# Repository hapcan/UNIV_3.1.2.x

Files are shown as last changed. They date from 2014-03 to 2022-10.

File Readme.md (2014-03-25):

UNIV 3.1.2.x
============

TOUCH BUTTON MODULE - 6 sensors &amp; 1-wire temperature sensor

Device webpage: http://hapcan.com/devices/universal/univ_3/univ_3-1-2-x/

Hardware created in Eagle PCB Software http://www.cadsoftusa.com/

Firmware created in Microchip MPLAB http://www.microchip.com/mplabide/ in assembly language

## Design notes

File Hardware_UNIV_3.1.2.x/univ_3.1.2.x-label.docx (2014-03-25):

| | TOUCH BUTTON TYPE UNIV 3.1.2.x S/N 0000056Ah
| | PRZYCISK DOTYKOWY TYP UNIV 3.1.2.x S/N 0000056Ah

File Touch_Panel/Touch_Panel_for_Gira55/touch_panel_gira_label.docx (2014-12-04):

| OFF 18° 21° HAPCAN | HAPCAN

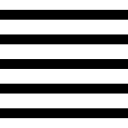
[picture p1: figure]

| 15min
HAPCAN | | Icons thanks to http://icons8.com/
How to prepare touch panel labels 1. Print required design on adhesive transparent foil and let it dry 2. Cut A4 page along the red line into single labels 3. Put another protective adhesive transparent foils on top of the printed ones 4. Cut the label to the required size along the light gray line 5. Stick the label on the Touch Panel and press it precisely 6. Cut temperature sensor hole using thin saw file with the sharp end | Instrukcja wykonania etykiety panelu dotykowego 1. Wydrukuj przygotowaną etykietę na samoprzylepnej przezroczystej folii i pozwól jej wyschnąć 2. Rozetnij stronę A4 wzdłuż czerwonej linii na pojedyncze etykiety 3. Przyklej jeszcze jedną ochronną wierzchnią warstwę samoprzylepnych folii na wydrukowane etykiety 4. Przytnij etykietę do wymaganego rozmiaru wzdłuż jasnoszarej linii 5. Przyklej etykietę na panel dotykowy i starannie dociśnij 6. Wytnij otwór sensora temperatury używając cienkiego okrągłego pilnika modelarskiego z ostrym końcem

This template link: https://github.com/hapcan/UNIV_3.1.2.x/blob/master/Touch_Panel/Touch_Panel_for_Gira55/touch_panel_gira_label.docx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

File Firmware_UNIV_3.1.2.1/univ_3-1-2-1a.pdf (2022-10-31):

## BACK BOX TOUCH BUTTON FIRMWARE

# UNIV 3.1.2.1

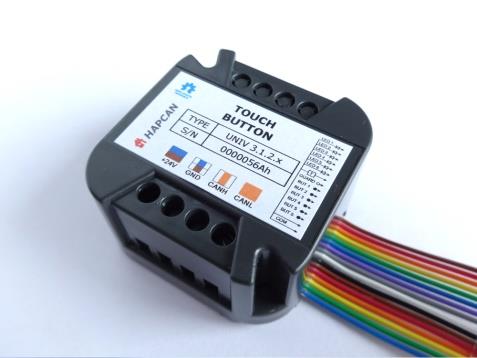
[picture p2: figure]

© 2017 hapcan.com | univ_3-1-2-1a.pdf - page 1 / 9

### 1. Features

- 6 channel touch button module.
- Another button is recognized when all sensors are touched at the same time.
- 7 types of button behaving is recognized: button pressed, released, pressed for 400ms, pressed for 4s, released within 400ms, released between 400ms and 4s, released after 4s
- There is a 20ms reaction time. Button has to be pressed for at least 20ms to activate module. It avoids contacts bouncing.
- 6 LEDs can be connected to indicate status of other devices on the network.
- Included temperature, thermostat and PWM controller feature when Dallas sensor is connected.
- Temperature measurement in range -55°C to +125°C with 0.0625°C resolution
- Setpoint value in range -55°C to +125° C with 0.0625°C resolution
- Hysteresis value adjustable from 0.0625 to 16.000°C with 0.0625°C resolution
- 10 control instructions
- 3 blocking instructions
- Allows defining up to 128 CAN messages which can indirectly control the module
- Self-control feature – pressed button can control LEDs in the same module
- Allows writing notes in the processor memory
- Uptime counter
- Health check monitor
- Transmit (42 messages) and receive (42 messages) FIFO buffers

### 2. Compatibility

- Firmware for UNIV 3.1.2.x module
- Firmware can be uploaded into processor with bootloader version 3.1 or compatible.
- Firmware is not fully compatible with previous UNIV 3.1.2.0. The temperature sensor parameters must be configure again.

### 3. Firmware version

UNIV | 3 | . | 1 | . | 2 | . | 1
firmware version
application version (back box touch button) application type (button)
processor version
universal processor

### 4. Communication Frames (messages)

### 4.1. Button message

Module sends message to the bus, when status of input changes. Module is able to distinguish a few types of button behaving: pressed, released, pressed for 400ms, pressed for 4s, released within 400ms, released between 400ms and 4s , released after 4s. For each situation the unique message is sent to the bus. It is possible to choose for each button separately what massages should be sent. Button 7 is recognized when all sensors are touched at the same time.
This firmware controls LEDs connected to switches. LED can be toggled by message received from the bus or locally by pressed button.

Table 1. BUTTON frame (0x301)
Frame type | Flags | Module | Group | D0 | D1 | D2 | D3 | D4 | D5 | D6 | D7
0x301 | 3 | 2 | 1 | 0 | Node Nr | Group Nr | 0xFF | 0xFF | CHANNEL | BUTTON | LED | 0xFF | 0xFF | 0xFF
0x301 | – universal module frame, button
3 | - | - not used flag, read as “0”
2 | - | - not used flag, read as “0”
1 | - | - not used flag, read as “0”
0 | RE | - response flag. Flag is equal “1” if node was requested. If flag is equal „0” it means that status of input has just changed.
Node Nr | - message sender node number
Group Nr | - message sender group number
CHANNEL | - input channel 0x01 (button 1) – 0x07 (button 7)
BUTTON | - actual input status
| | 0x00 – open 0xFF – closed
| | 0xFE – closed and held for 400ms 0xFD – closed and held for 4s
| | 0xFC – closed and open within 400ms 0xFB – closed and open between 400ms and 4s 0xFA – closed and open after 4s
LED | - actual LED status 0x00 – off, 0xFF – on

### 4.2. Touch button parameters

This frame is sent only as response to STATUS REQUEST (0x109).

Table 2. TOUCH BUTTON PARAMETERS FRAME (0x301)
Frame type | Flags | Module | Group | D0 | D1 | D2 | D3 | D4 | D5 | D6 | D7
0x301 | 0x1 | Node Nr | Group Nr | 0xFF | 0xFF | CHANNEL | SAMPH | SAMPL | BASEH | BASEL | TRIMBITS
0x3011 | - universal module button frame, response to STATUS REQUEST
Node Nr | - message sender node number
Group Nr | - message sender group number
CHANNEL | - input channel 0x21 (button 1) – 0x06 (button 6)
SAMP | - current input status SAMPH:SAMPL (0x0000 – 0x0FFF)
BASE | - current baseline status (when sensor is not touched) BASEH:BASEL (0x0000 – 0x0FFF)
TRIMBITS | - describes calibrated sensor current for particular channel (this byte is copied from
CTMUICON processor register)
011111 11 - 550us +62%
011110 11 - 550us +60%
011101 11 - 550us +58%
…
000001 11 - 550us +2%
000000 11 - 550us
111111 11 - 550us - 2%
…
100011 11 - 550us - 58%
100010 11 - 550us - 60%
100001 11 - 550us - 62%
000000 00 – means calibration error

### 4.3. Current temperature message

The module sends message when sensor temperature changes by value (0.0625-15.9375°C) defined in configuration. The frame contains temperature setpoint. The setpoint can be adjusted by other modules on the network.

Table 3. CURRENT TEMPERATURE frame (0x304)
Frame type | Flags | Module | Group | D0 | D1 | D2 | D3 | D4 | D5 | D6 | D7
0x304 | 3 | 2 | 1 | 0 | Node Nr | Group Nr | 0xFF | 0xFF | 0x11 | TEMPMSB | TEMPLSB | SETPOMSB | SETPOLSB | HYSTER
0x304 | – thermometer
3 | - | - not used flag, read as “0”
2 | - | - not used flag, read as “0”
1 | - | - not used flag, read as “0”
0 | RE | - response flag. Flag is equal “1” if node was requested. If flag is equal „0” it means that status of output has just changed.
Node Nr | - message sender node number
Group Nr | - message sender group number
0x11 | - data type in message (0x11 - temperature frame)
TEMPMSB | - most significant byte of measured temperature 0xFC90 – 0x07D0 (-55°C - +125°C),
| | resolution 0.0625°C
TEMPLSB | - least significant byte of measured temperature
SETPOMSB | - most significant byte of thermostat value 0xFC90 – 0x07D0 (-55°C - +125°C),
| | resolution 0.0625°C
SETPOLSB | - least significant byte of thermostat value
HYSTER | - switching hysteresis 0x00 – 0xFF (0.0625 – 16.0000°C), resolution 0.0625°C

The temperature data is presented by TEMPMSB and TEMPLSB registers as 12bit sign extended two’s complement number. The sign bits ‘S’ indicate if temperature is positive or negative. For positive numbers S=0 and for negative S=1. Please refer to Dallas sensor datasheet for details.

TEMPMSB
S | S | S | S | S | 2
6 | 2
5 | 2

4
TEMPLSB
2
3 | 2
| 2 | 2
| | 1 | 2
| | | 0 | 2
| | | | -1 | 2
-2 | 2
-3 | 2

-4

Table 4. Temperature register format for Current Temperature frame.

### 4.4. Thermostat message

When measured temperature drops below, or rises above setpoint, the module sends thermostat message. Hysteresis value makes module to not react immediately for temperature changes around switching point. Adequate hysteresis can be set 0.0625 – 16.0000°C with resolution 0.0625°C. This message can toggle other modules on the network.

Table 5. THERMOSTAT frame
Frame type | Flags | Module | Group | D0 | D1 | D2 | D3 | D4 | D5 | D6 | D7
0x304 | 3 | 2 | 1 | 0 | Node Nr | Group Nr | 0xFF | 0xFF | 0x12 | POSITION THERM | 0xFF | 0xFF | 0xFF | THERM STATE
0x304 | – thermometer
3 | - | - not used flag, read as “0”
2 | - | - not used flag, read as “0”
1 | - | - not used flag, read as “0”
0 | RE | - response flag. Flag is equal “1” if node was requested. If flag is equal „0” it means that status of output has just changed.
Node Nr | - message sender node number
Group Nr | - message sender group number
0x12 | - data type in message (0x12 - thermostat frame)
| | THERM
| | POSITION
- current thermostat status (0x00 - temperature below setpoin, 0xFF - temperature
| | above setpoint, 0x80 – power up value)
| | THERM STATE
- thermostat state (0x00 – turned off, 0xFF – turned on)

### 4.5. Temperature controller message

The module can operate as a temperature regulator with PWM output. You can specify the PWM period (1-256 minutes) and the duty cycle which depends on temperature error up to 2°C with 0.0625°C resolution (32 positions for heating and 32 for cooling). The controller has a sensitivity setting feature.

Module sends this message when:
1. temperature error has changed and is equal to zero;
2. temperature error has changed and this change is greater or equal to controller sensitivity (value 0,0625°C - 16,0000°C) set in module configuration;
3. begins new period of PWM (value 1 – 255 minutes) set in module configuration;
4. there is a change of PWM state from high to low state. For PWM 100% value, there is no change, so no message is sent;
5. message cyclical transmission time has elapsed, if defined in the configuration (value 1-255 minutes);
6. controller has been turned off or on;
7. module has been asked for status.

Table 6. CONTROLLER frame
Frame type | Flags | Module | Group | D0 | D1 | D2 | D3 | D4 | D5 | D6 | D7
0x304 | 3 | 2 | 1 | 0 | Node Nr | Group Nr | 0xFF | 0xFF | 0x13 | HEAT PWM STATE | HEAT PWM VALUE | COOL PWM STATE | COOL PWM VALUE | CTRL STATE
0x304 | – thermometer
3 | - | - not used flag, read as “0”
2 | - | - not used flag, read as “0”
1 | - | - not used flag, read as “0”
0 | RE | - response flag. Flag is equal “1” if node was requested. If flag is equal „0” it means that status of output has just changed.
Node Nr | - message sender node number
Group Nr | - message sender group number
0x13 | - data type in message (0x13 - controller frame)
| | HEAT PWM STATE
- heating controller PWM state (0x00 – PWM is off „0”, 0xFF – PWM is on „1”)

HEAT PWM
VALUE
- heating controller PWM value 0-255 (0x00 – 0xFF)

COOL PWM
STATE
- cooling controller PWM state (0x00 – PWM is off „0”, 0xFF – PWM is on „1”)

COOL PWM
VALUE
- cooling controller PWM value 0-255 (0x00 – 0xFF)

CTRL
STATE
- controller state (0x00 – turned off, 0xFF – turned on)

### 4.6. Temperature sensor error frame

The module sends this message when a temperature sensor reading error has occurred and:
1 elapsed time of cyclic sending, if defined in the configuration (value in the range 1-255 minutes);
2 module was asked for status.

Table 7. SENSOR ERRROR FRAME
Frame type | Flags | Module | Group | D0 | D1 | D2 | D3 | D4 | D5 | D6 | D7
0x304 | 3 | 2 | 1 | 0 | Node Nr | Group Nr | 0xFF | 0xFF | 0xF0 | ERROR | 0xFF | 0xFF | 0xFF | 0xFF
0x304 | – thermometer
3 | - | - not used flag, read as “0”
2 | - | - not used flag, read as “0”
1 | - | - not used flag, read as “0”
0 | RE | - response flag. Flag is equal “1” if node was requested. If flag is equal „0” it means that status of output has just changed.
Node Nr | - message sender node number
Group Nr | - message sender group number
0xF0 | - data type in message (0xF0 – temperature sensor error frame)
ERROR | - error codes
| | 0x01 – sensor not connected
| | 0x02 – connected more than one sensor or connected wrong type of sensor 0x03 – connected wrong type of sensor 0x04 – communication problem on 1-wire network (CRC problem)

### 4.7. Status request

Status of module can be checked by sending from computer STATUS REQUEST frame (0x109) (Table 8).

Table 8. STATUS REQUEST frame (0x109).
Frame type | Flags | Module | Group | D0 | D1 | D2 | D3 | D4 | D5 | D6 | D7
0x109 | 0x0 | COMP ID1 | COMP ID2 | 0xXX | 0xXX | Node Nr | Group Nr | 0xXX | 0xXX | 0xXX | 0xXX
0x1090 | – STATUS REQUEST frame
COMP ID1 | - computer identifier (must be unique on the network)
COMP ID2 | - computer identifier (must be unique on the network)
Node Nr | - node number of requested module
Group Nr | - group number of requested module
0xXX | - inessential data

As response the module will send status frames (Table 9). Meaning of bytes is the same as in Table 1, 3, 5, 6 or 7. Instead of sending current temperature and thermostat frames, the module can send error frame.

Table 9. Response to STATUS REQUEST.
BUTTON FRAMES
Frame type | Flags | Module | Group | D0 | D1 | D2 | D3 | D4 | D5 | D6 | D7
0x301 | 0x1 | Node Nr | Group Nr | 0xFF | 0xFF | 0x01 | BUTTON | LED | 0xFF | 0xFF | 0xFF
Frame type | Flags | Module | Group | D0 | D1 | D2 | D3 | D4 | D5 | D6 | D7
0x301 | 0x1 | Node Nr | Group Nr | 0xFF | 0xFF | 0x02 | BUTTON | LED | 0xFF | 0xFF | 0xFF
…
Frame type | Flags | Module | Group | D0 | D1 | D2 | D3 | D4 | D5 | D6 | D7
0x301 | 0x1 | Node Nr | Group Nr | 0xFF | 0xFF | 0x06 | BUTTON | LED | 0xFF | 0xFF | 0xFF
TOUCH BUTTON PARAMETERS FRAMES
Frame type | Flags | Module | Group | D0 | D1 | D2 | D3 | D4 | D5 | D6 | D7
0x301 | 0x1 | Node Nr | Group Nr | 0xFF | 0xFF | 0x21 | SAMPH | SAMPL | BASEH | BASEL | TRIMBITS
…
Frame type | Flags | Module | Group | D0 | D1 | D2 | D3 | D4 | D5 | D6 | D7
0x301 | 0x1 | Node Nr | Group Nr | 0xFF | 0xFF | 0x26 | SAMPH | SAMPL | BASEH | BASEL | TRIMBITS
TEMPERATURE, THERMOSTAT CONTROLLER FRAMES
Typ ramki | Flagi | Moduł | Grupa | D0 | D1 | D2 | D3 | D4 | D5 | D6 | D7
0x304 | 0x1 | Node Nr | Group Nr | 0xFF | 0xFF | 0x11 | TEMPMSB | TEMPLSB | SETPOMSB | SETPOLSB | HYSTER
Typ ramki | Flagi | Moduł | Grupa | D0 | D1 | D2 | D3 | D4 | D5 | D6 | D7
0x304 | 0x1 | Node Nr | Group Nr | 0xFF | 0xFF | 0x12 | POSITION THERM | 0xFF | 0xFF | 0xFF | THERM STATE
Typ ramki | Flagi | Moduł | Grupa | D0 | D1 | D2 | D3 | D4 | D5 | D6 | D7
0x304 | 0x1 | Node Nr | Group Nr | 0xFF | 0xFF | 0x13 | HEAT PWM STATE | HEAT PWM VALUE | COOL PWM STATE | COOL PWM VALUE | CTRL STATE

### 4.8. Uptime request

Table 10. UPTIME REQUEST (0x113).
Frame type | Flags | Module | Group | D0 | D1 | D2 | D3 | D4 | D5 | D6 | D7
0x113 | 0x0 | COMP ID1 | COMP ID2 | 0xXX | 0xXX | Node Nr | Group Nr | 0xXX | 0xXX | 0xXX | 0xXX
0x1130 | – UPTIME REQUEST frame
COMP ID1 | - computer identifier (must be unique on the network)
COMP ID2 | - computer identifier (must be unique on the network)
Node Nr | - node number of requested module
Group Nr | - group number of requested module
0xXX | - inessential data

Table 11. Response to UPTIME REQUEST (0x113).
Frame type | Flags | Module | Group | D0 | D1 | D2 | D3 | D4 | D5 | D6 | D7
0x113 | 0x1 | Node Nr | Group Nr | 0xFF | 0xFF | 0xFF | 0xFF | UPTIME3 | UPTIME2 | UPTIME1 | UPTIME0
0x1131 | – Response to UPTIME REQUEST frame
Node Nr | - message sender node number
Group Nr | - message sender group number
UPTIME | - (UPTIME3*256³+UPTIME2*256²+UPTIME1*256¹+UPTIME3*256⁰
) in seconds

### 4.9. Health check request

Table 12. HEALTH CHECK - STATUS REQUEST (0x115).
Frame type | Flags | Module | Group | D0 | D1 | D2 | D3 | D4 | D5 | D6 | D7
0x115 | 0x0 | COMP ID1 | COMP ID2 | 0x01 | 0xXX | Node Nr | Group Nr | 0xXX | 0xXX | 0xXX | 0xXX
0x1150 | – HEALTH CHECK REQUEST frame
COMP ID1 | - computer identifier (must be unique on the network)
COMP ID2 | - computer identifier (must be unique on the network)
0x01 | - status request
Node Nr | - node number of requested module
Group Nr | - group number of requested module
0xXX | - inessential data

As response the module will send two frames (Table 13).

Table 13. Response to HEALTH CHECK - STATUS REQUEST (0x115).
Frame type | Flags | Module | Group | D0 | D1 | D2 | D3 | D4 | D5 | D6 | D7
0x115 | 0x1 | Node Nr | Group Nr | 0x01 | RXCNT | TXCNT | RXCNTMX | TXCNTMX | CANINTCNT | RXERRCNT | TXERRCNT
0x1151 | – Response to HEALTH CHECK REQUEST frame
Node Nr | - message sender node number
Group Nr | - message sender group number
0x01 | - frame 1 (current values)
RXCNT | - current level of receive FIFO buffer
TXCNT | - current level of transmit FIFO buffer
RXCNTMX | - maximum level of receive FIFO buffer since power up
TXCNTMX | - maximum level of transmit FIFO buffer since power up
CANINTCNT | - number of CAN interface restarts since power up
RXERRCNT | - current receive errors register
TXERRCNT | - current transmit errors register
Frame type | Flags | Module | Group | D0 | D1 | D2 | D3 | D4 | D5 | D6 | D7
0x115 | 0x1 | Node Nr | Group Nr | 0x02 | 0xFF | 0xFF | RXCNTMXE | TXCNTMXE | CANINTCNTE | RXERRCNTE | TXERRCNTE
0x1151 | – Response to HEALTH CHECK REQUEST frame
Node Nr | - message sender node number
Group Nr | - message sender group number
0x02 | - frame 2 (maximum values saved in eeprom memory)
RXCNTMXE | - maximum ever level of receive FIFO buffer
TXCNTMXE | - maximum ever level of transmit FIFO buffer
CANINTCNTE | - maximum ever number of CAN interface restarts
RXERRCNTE | - maximum ever receive errors
TXERRCNTE | - maximum ever transmit errors

To clear maximum values saved in eeprom memory the frame shown in Table 14 must be sent. There is no response to this message.

Table 14. HEALTH CHECK - CLEAR REQUEST (0x115).
Frame type | Flags | Module | Group | D0 | D1 | D2 | D3 | D4 | D5 | D6 | D7
0x115 | 0x0 | COMP ID1 | COMP ID2 | 0x02 | 0xXX | Node Nr | Group Nr | 0xXX | 0xXX | 0xXX | 0xXX
0x1150 | – HEALTH CHECK REQUEST frame
COMP ID1 | - computer identifier (must be unique on the network)
COMP ID2 | - computer identifier (must be unique on the network)
0x02 | - clear request
Node Nr | - node number of requested module
Group Nr | - group number of requested module
0xXX | - inessential data

### 5. Module control

The module can be controlled directly from PC, or indirectly by other modules. In both situation all instructions in the table below can be used. Blocking instructions (0xDD-0xDF ) can’t be used in direct control.

### 5.1. Control instruction

The Table 15 shows instructions, which can be executed by the module.

Table 15. Module control instructions

Instruction | Instruction coding | Description | Control
INSTR1 | INSTR2 | INSTR3 | INSTR4 | INSTR5 | INSTR6 | INSTR7 | INSTR8
TURN ON LED | 0x00 | LED1 | LED2 | 0xXX | 0xXX | 0xXX | 0xXX | 0xXX | It will turn on chosen LEDs, and the rest will stay unchanged. | √ | √
TURN OFF LED | 0x01 | LED1 | LED2 | 0xXX | 0xXX | 0xXX | 0xXX | 0xXX | It will turn off chosen LEDs, and the rest will stay unchanged. | √ | √
TOGGLE LED | 0x02 | LED1 | LED2 | 0xXX | 0xXX | 0xXX | 0xXX | 0xXX | It will toggle chosen LEDs, and the rest will stay unchanged. | √ | √

Direct

Indirect

0xXX – inessential data
LED1 | Description
0x01 | - (00000001) - only LED1
0x02 | - (00000010) - only LED2
0x03 | - (00000011) - LED1 & LED2
0x04 | - (00000100) - only LED3
…
0x3F | - ‘00111111’ - LED1, 2, 3, 4, 5, 6
bit <5> - LED6, bit <4> - LED5, bit <3> - LED4, bit <2> - LED3, bit <1> - LED2, bit <0> - LED1
SET SETPOINT TO | 0x03 | THMSB | THLSB | 0xXX | 0xXX | 0xXX | 0xXX | 0xXX | It will set thermostat to value indicated in THER1 & THER2 registers | √ | √
DECREASE SETPOINT BY | 0x04 | STEP | 0xXX | 0xXX | 0xXX | 0xXX | 0xXX | 0xXX | It will decrease thermostat by value STEP*0,0625°C | √ | √
INCREASE SETPOINT BY | 0x05 | STEP | 0xXX | 0xXX | 0xXX | 0xXX | 0xXX | 0xXX | It will increase thermostat by value STEP*0,0625°C | √ | √

0xXX – inessential data
THMSB | THLSB | Description
0xFC90 - 0x07D0 | | Thermostat value 0xFC90 – 0x07D0 (-55°C - +125°C), resolution 0,0625°C, where THMSB – most significant byte, THLSB – least significant byte
STEP | Description
0x01 | - thermostat value will be changed (decreased or increased) by 1*0,0625°C=0,0625°C value
0x02 | - thermostat value will be changed (decreased or increased) by 2*0,0625°C=0,1250°C value
…
0xFF | - thermostat value will be changed (decreased or increased) by 255*0,0625°C=15,9375 °C value
0x00 | - thermostat value will be changed (decreased or increased) by 256*0,0625°C=16,0000 °C value
TURN OFF THERMOSTAT/CONTROLLER | 0x06 | MODULE | 0xXX | 0xXX | 0xXX | 0xXX | 0xXX | 0xXX | Turns off chosen modules | √ | √
TURN ON THERMOSTAT/CONTROLLER | 0x07 | MODULE | 0xXX | 0xXX | 0xXX | 0xXX | 0xXX | 0xXX | Turns on chosen modules | √ | √
TOGGLE THERMOSTAT/CONTROLLER | 0x08 | MODULE | 0xXX | 0xXX | 0xXX | 0xXX | 0xXX | 0xXX | Toggles chosen modules | √ | √

0xXX – inessential data
MODULE | Description
0x01 | - (00000001) - only THERMOSTAT
0x02 | - (00000010) - only CONTROLLER
0x03 | - (00000011) – THERMOSTAT & CONTROLLER
bit <1> - CONTROLLER, bit <0> - THERMOSTAT
DEACTIVATE BUTTONS FOR | 0x09 | TIME | 0xXX | 0xXX | 0xXX | 0xXX | 0xXX | 0xXX | Deactivates all buttons for time defined in TIME register.
Instruction is used for touch panel cleaning. | √ | √

0xXX – inessential data
TIME | Description
0x01 | - deactivates buttons for 1s
0x02 | - deactivates buttons for 2s
…
0xFF | - deactivates buttons for 255s
ENABLE BOX | 0xDD | BoxX | BoxY | 0xXX | 0xXX | 0xXX | 0xXX | 0xXX | It enables chosen boxes – these boxes will be compared with next received message from the bus. | √
DISABLE BOX | 0xDE | BoxX | BoxY | 0xXX | 0xXX | 0xXX | 0xXX | 0xXX | It disables chosen boxes – these boxes will be passed when next message arrives from the bus. | √
TOGGLE BOX | 0xDF | BoxX | BoxY | 0xXX | 0xXX | 0xXX | 0xXX | 0xXX | It toggles boxes – enables when they are disabled and vice versa | √

0xXX – inessential data
BoxX | Description
0x00 | - from Box 1
0x01 | - from Box 2
…
0x7F | - from Box 128
BoxY | Description
0x00 | + 0 -(and not anyone else)
0x01 | + 1 -( and 1 following)
…
0x7F | +128 -( and 128 following)

### 5.2. Direct control

It is possible to control module by sending DIRECT CONTROL message. The message contains instruction, which will be executed by the module.

Table 15. DIRECT CONTROL frame (0x10A).
Frame type | Flags | Module | Group | D0 | D1 | D2 | D3 | D4 | D5 | D6 | D7
0x10A | 0x0 | COMP ID1 | COMP ID2 | INSTR1 | INSTR2 | Node Nr | Group Nr | INSTR3 | INSTR4 | INSTR5 | INSTR6
0x10A0 | – DIRECT CONTROL frame
COMP ID1 | - computer identifier (must be unique on the network)
COMP ID2 | - computer identifier (must be unique on the network)
Node Nr | - node number of requested module
Group Nr | - group number of requested module
INSTR1-6 | - 6 byte instruction to be executed

### 5.3. Indirect control

Indirect control means that module will react to messages sent by other modules on the network. It depends on configuration programmed into the module boxes (memory cells).
This firmware has feature to set simple conditions of executing instruction. To do so, you can use blocking instruction (0xDD – 0xDF) shown in Table 14.

### 6. Configuration

Parameters that can be configured with this firmware:
- Module identifier (module number and group number);
- Module description (16 chars);
- Button settings
- Touch button settings
- Thermostat value on power up;
- Temperature offset
- Thermostat hysteresis;
- Text notes;
- Linking device with other modules (indirect control of module). Configuration process can be done using HAPCAN Programmer.

### 6.1. Module identifier

Every module on the network must have unique identifier. The identifier is made of two bytes, module number (1 byte) and group number (1 byte). Identifier of the Ethernet Interface can be changed in HAPCAN Programmer in software settings.

### 6.2. Module description

Every module can have 16 char description, which makes easier for user (programmer) to distinguish nodes.

### 6.3. Button settings

For each button it is possible to configure what type of button behaving is recognized by module. Module can recognize when:
- button is pressed,
- button is released,
- pressed and held for 400ms,
- pressed and held for 4s,
- pressed and released within 400ms (quick click),
- pressed and released between 400ms and 4s,
- pressed and released after 4s.
For each behaving a separate message will be sent on the bus.
WARNING: It is very important to choose only messages which will be used on the network to keep traffic on the bus as low as possible.

### 6.4. Button settings

For each touch sensor separately can be defined press and release threshold as offsets from the baseline.

### 6.5. Thermostat/Controller state on power up

There are 3 possible settings: thermostat / regulator on, off, and the state before power failure, which must be unchanged for 6 seconds before turning off the power, to be remembered.

### 6.6. Setpoint value on power up

The thermostat value on power up can be set between 0xFC90 – 0x07D0 (-55°C - +125°C). It can also be chosen last adjusted value before power disconnection (0x0800).

### 6.7. Temperature offset

It is possible to calibrate the thermometer by setting temperature offset, which will be added to measured temperature. Temperature with added offset will be displayed as current temperature and will be used to check against the thermostat. The temperature offset value can be chosen from range 0xFC90 – 0x07D0 (-55°C -+125°C) with 0.0625°C resolution. If no calibration is needed the offset should be set to 0x0000.

### 6.8. Temperature sensitivity

This parameter defines the minimum change of sensor temperature when the module sends the temperature message.

### 6.9. Periodical messages

This parameter defines the period between cyclical temperature, thermostat and controller frames. The parameter is defined individually for temperature, thermostat and controller. The period can be set between 0x01-0xFF (1min
- 255min). The 0x00 value disables the cyclic sending messages.

### 6.10. Thermostat hysteresis

Hysteresis prevents module from switching constantly around setpoint value. Thermostat will be switched to 0xFF (high state) if temperature rises above (setpoint + hysteresis). It will be switched to 0x00 (low state) if temperature drops below (setpoint – hysteresis) (see Figure 1). The hysteresis value can be chosen from 0x00 to 0xFF (0.0625°C tp 16.0000°C) with 0.0625°C resolution.

TTH – Thermostat switching point TH – Thermostat in high state TL – Thermostat in low state HYST – Hysteresis value

Figure 1. Switching point and hysteresis.

### 6.11. Controller sensitivity

Specifies the minimum temperature error change for controller to react. The value can be set between 0.0625°C - 16.0000°C.

### 6.12. The controller PWM period

The period of the PWM signal can be set in the range from 1 - 255 minutes. This setting is common to control heating and cooling.

### 6.13. Temperature error to PWM duty cycle mapping table

Table allows temperature error to PWM signal duty cycle mapping. The table contains 32 fields or temperature error from 0.0625 to 2.0000°C (resolution 0.0625°C). The duty cycle values: 0x00-0xFF (0% -100%). The module has two tables: one for heating and another for cooling control. The duty cycle for temperature error greater than 2.0000°C is the same as for the value of 2.0000°C.

6.14. Text notes.
Up to 1024 characters can be written into processor’s memory.

### 6.15. Linking devices

The module has 128 memory cells (boxes). Each box can contain information about message sent by other node, and instruction which will be executed when that message is received.

### 7. License

HAPCAN Home Automation Project firmware, Copyright (C) 2017 hapcan.com

This program is free firmware: you can redistribute it and/or modify it under the terms of the GNU General Public License as published by the Free Software Foundation, either version 3 of the License, or (at your option) any later version.

This firmware is distributed in the hope that it will be useful, but WITHOUT ANY WARRANTY; without even the implied warranty of MERCHANTABILITY or FITNESS FOR A PARTICULAR PURPOSE. See the GNU General Public License for more details.

You should have received a copy of the GNU General Public License along with this firmware. If not, see http://www.gnu.org/licenses/gpl-3.0.html.

### 8. Document version

File | Note | Date
univ_3-1-2-1a.pdf | Initial version | August 2017

HYST

TTH

TL

TH

T [°C]

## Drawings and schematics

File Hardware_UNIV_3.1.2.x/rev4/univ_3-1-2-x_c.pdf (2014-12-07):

## BACK BOX TOUCH BUTTON

# UNIV 3.1.2.x

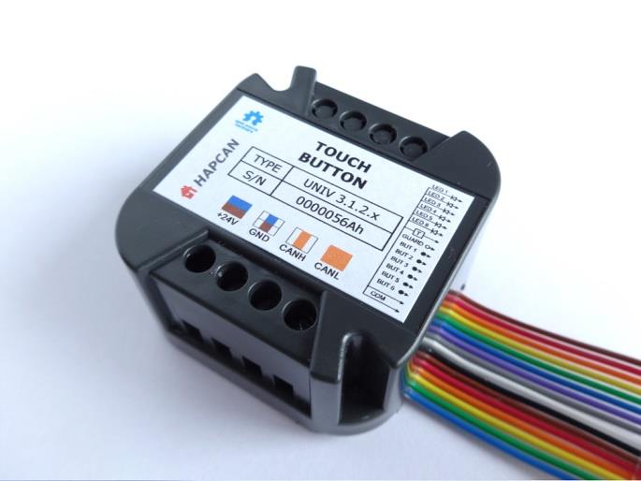
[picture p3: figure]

© 2014 hapcan.com | univ_3-1-2-x_c.pdf - page 1 / 5

### 1. Features

- 6 channel touch button module. Up to 6 sensors can be connected to the module. There is no front panel with touch sensors included. Please see Microchip AN1492 and AN1334 notes to find out how to design sensors.
- Possibility to connect 6 LEDs to indicate status of other nodes
- Uses 1-wire digital sensors DS18B20, or DS1822.
- Measures temperatures from -55°C to +125°C.
- Accuracy ±0.5°C when used with DS18B20+, or ±2.0°C with DS1822.
- 12bits temperature resolution.
- Operation voltage 10-24V
- Current consumption 18mA with 6 LEDs turned on
- For deep back box mounting
- Dimensions 44x44x25 mm
- Operating of module depends on firmware uploaded into it.
- Schematic and PCB design can be downloaded from hapcan.com site

### 2. Application version

UNIV | 3 | . | 1 | . | 2 | . | x
firmware version
application version (touch button) application type (button)
processor version
universal processor

### 3. Technical data

Bus side
Parameter | Symbol | Value | Unit
Power supply voltage | Us | 10-24V | V
Current consumption without LEDs | Is | 8 | mA
Maximum current consumption with 6 LEDs turned on | Ismax | 18 | mA
Bus connector type | 4 terminal blocks 1.5mm²

Button input
Parameter | Symbol | Value | Unit
Connector type | Stranded ribbon cable
Size of input wire | s | 0.13 26 | mm² AWG
Length of input wire | l | 0.25 | m

Temperature sensor
Parameter | Symbol | Value | Unit
Operating temperature | T | -55 - +125 | °C
Operating temperature resolution | TRES | 0.0625 | °C
Temperature accuracy | TERR | DS18B20+: ±2 ±0.5 (-10°C - +85°C) DS1822: ±3 ±2 (-10°C - +85°C) | °C

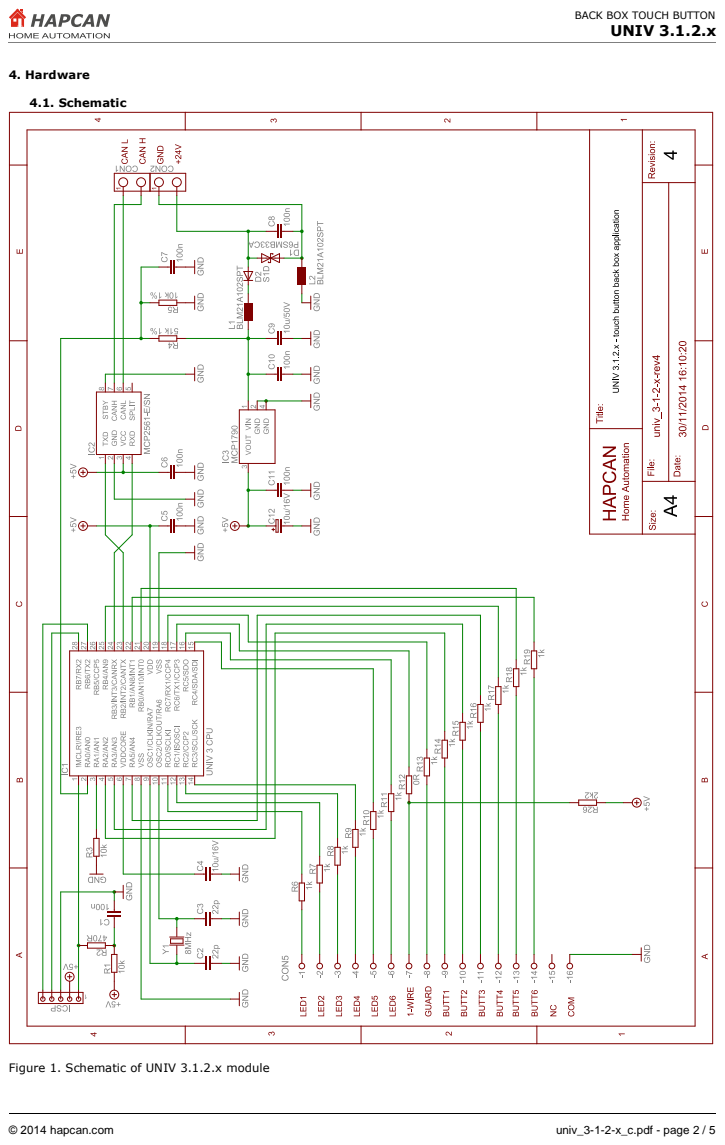
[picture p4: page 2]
4. Hardware; 4.1. Schematic

Figure 1. Schematic of UNIV 3.1.2.x module

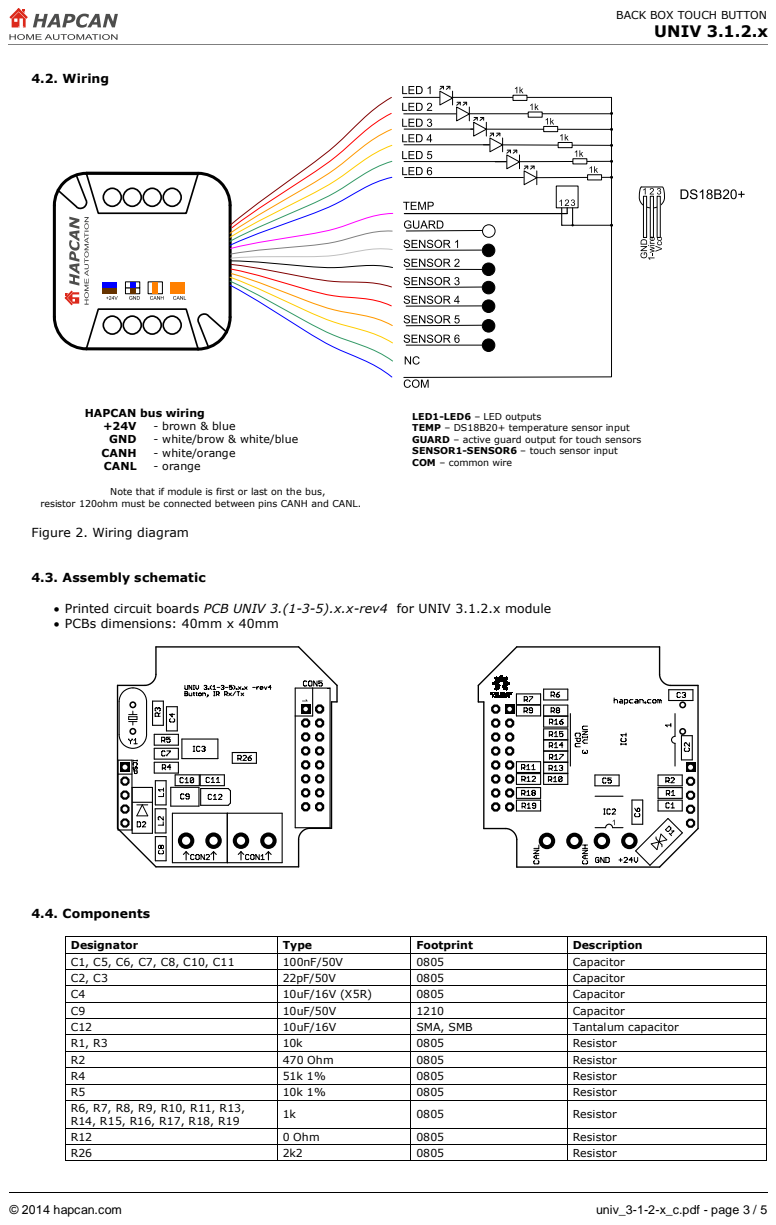
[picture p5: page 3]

LED1-LED6 – LED outputs
TEMP – DS18B20+ temperature sensor input
GUARD – active guard output for touch sensors
SENSOR1-SENSOR6 – touch sensor input
COM – common wire

Note that if module is first or last on the bus,

resistor 120ohm must be connected between pins CANH and CANL.

• Printed circuit boards PCB UNIV 3.(1-3-5).x.x-rev4 for UNIV 3.1.2.x module
• PCBs dimensions: 40mm x 40mm

Designator | Type | Footprint | Description
C1, C5, C6, C7, C8, C10, C11 | 100nF/50V | 0805 | Capacitor
C2, C3 | 22pF/50V | 0805 | Capacitor
C4 | 10uF/16V (X5R) | 0805 | Capacitor
C9 | 10uF/50V | 1210 | Capacitor
C12 | 10uF/16V | SMA, SMB | Tantalum capacitor
R1, R3 | 10k | 0805 | Resistor
R2 | 470 Ohm | 0805 | Resistor
R4 | 51k 1% | 0805 | Resistor
R5 | 10k 1% | 0805 | Resistor
R6, R7, R8, R9, R10, R11, R13, R14, R15, R16, R17, R18, R19 | 1k | 0805 | Resistor

R12 | 0 Ohm | 0805 | Resistor
R26 | 2k2 | 0805 | Resistor

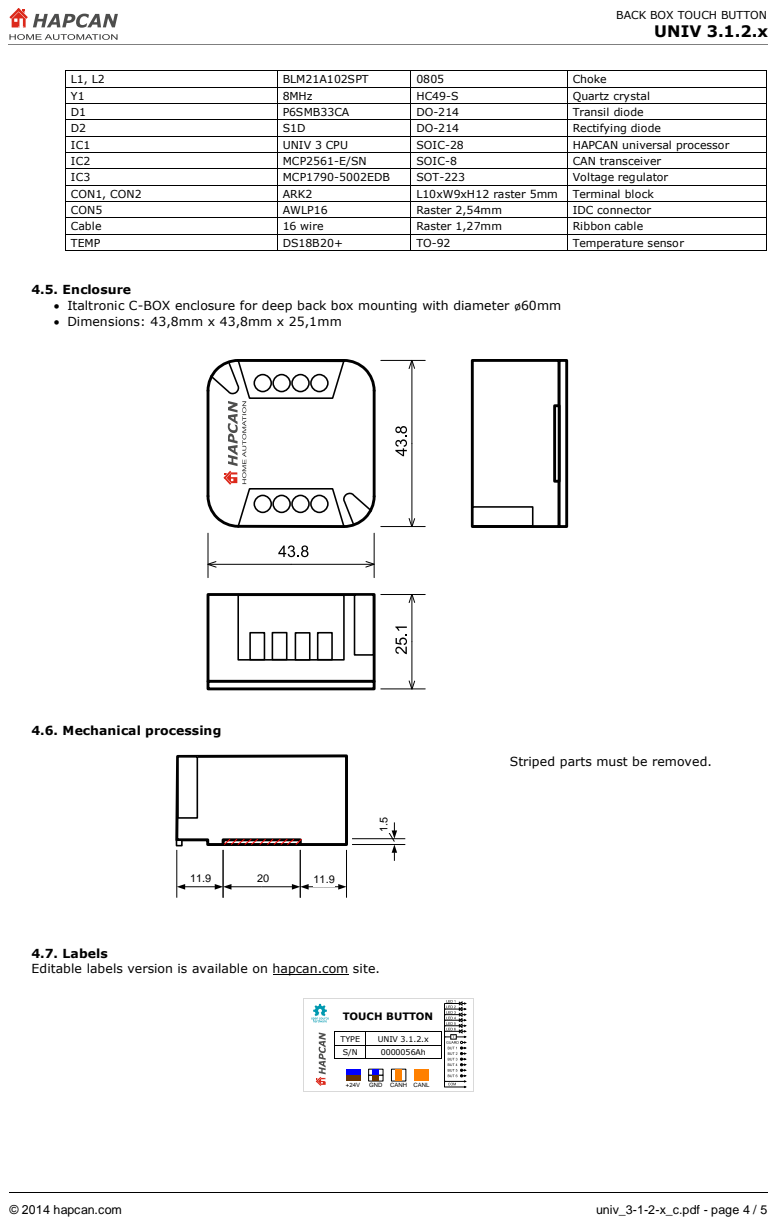
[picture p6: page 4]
4.6. Mechanical processing; TOUCH BUTTON; GND; CANH CANL

L1, L2 | BLM21A102SPT | 0805 | Choke
Y1 | 8MHz | HC49-S | Quartz crystal
D1 | P6SMB33CA | DO-214 | Transil diode
D2 | S1D | DO-214 | Rectifying diode
IC1 | UNIV 3 CPU | SOIC-28 | HAPCAN universal processor
IC2 | MCP2561-E/SN | SOIC-8 | CAN transceiver
IC3 | MCP1790-5002EDB | SOT-223 | Voltage regulator
CON1, CON2 | ARK2 | L10xW9xH12 raster 5mm | Terminal block
CON5 | AWLP16 | Raster 2,54mm | IDC connector
Cable | 16 wire | Raster 1,27mm | Ribbon cable
TEMP | DS18B20+ | TO-92 | Temperature sensor

4.5. Enclosure
• Italtronic C-BOX enclosure for deep back box mounting with diameter ø60mm
• Dimensions: 43,8mm x 43,8mm x 25,1mm

Striped parts must be removed.

4.7. Labels
Editable labels version is available on hapcan.com site.

TYPE | UNIV 3.1.2.x
S/N | 0000056Ah

### 5. Commissioning

### 5.1. CPU voltage measurement

After verifying the correctness and quality of the soldering, the bus voltage should be connected while measuring the processor voltage. To do this, connect a voltmeter to pins 2 and 3 of the ICSP connector. Processor supply voltage should be about 5V.

Figure 3. CPU voltage measurement

### 5.2. Checking the CPU clock

Proper operation of the CPU can be checked by temporarily connecting the LED to pins 3 and 5 of the ICSP connector. When device is powered, the LED should light up four times in the sequence 1 second on - 1 second off
- 1 second on. The LED lights up only once for 50ms, if the processor is in programming mode.

Figure 4. Checking the CPU clock
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

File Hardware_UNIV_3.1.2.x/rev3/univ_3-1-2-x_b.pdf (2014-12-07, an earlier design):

## BACK BOX TOUCH BUTTON

# UNIV 3.1.2.x


© 2014 hapcan.com | univ_3-1-2-x_b.pdf - page 1 / 5

### 1. Features

- 6 channel touch button module. Up to 6 sensors can be connected to the module. There is no front panel with touch sensors included. Please see Microchip AN1492 and AN1334 notes to find out how to design sensors.
- Possibility to connect 6 LEDs to indicate status of other nodes
- Uses 1-wire digital sensors DS18B20, or DS1822.
- Measures temperatures from -55°C to +125°C.
- Accuracy ±0.5°C when used with DS18B20+, or ±2.0°C with DS1822.
- 12bits temperature resolution.
- Operation voltage 10-24V
- Current consumption 18mA with 6 LEDs turned on
- For deep back box mounting
- Dimensions 44x44x25 mm
- Operating of module depends on firmware uploaded into it.
- Schematic and PCB design can be downloaded from hapcan.com site

### 2. Application version

UNIV | 3 | . | 1 | . | 2 | . | x
firmware version
application version (touch button) application type (button)
processor version
universal processor

### 3. Technical data

Bus side
Parameter | Symbol | Value | Unit
Power supply voltage | Us | 10-24V | V
Current consumption without LEDs | Is | 8 | mA
Maximum current consumption with 6 LEDs turned on | Ismax | 18 | mA
Bus connector type | 4 terminal blocks 1.5mm²

Button input
Parameter | Symbol | Value | Unit
Connector type | Stranded ribbon cable
Size of input wire | s | 0.13 26 | mm² AWG
Length of input wire | l | 0.25 | m

Temperature sensor
Parameter | Symbol | Value | Unit
Operating temperature | T | -55 - +125 | °C
Operating temperature resolution | TRES | 0.0625 | °C
Temperature accuracy | TERR | DS18B20+: ±2 ±0.5 (-10°C - +85°C) DS1822: ±3 ±2 (-10°C - +85°C) | °C

## UNIV 3.1.2.x

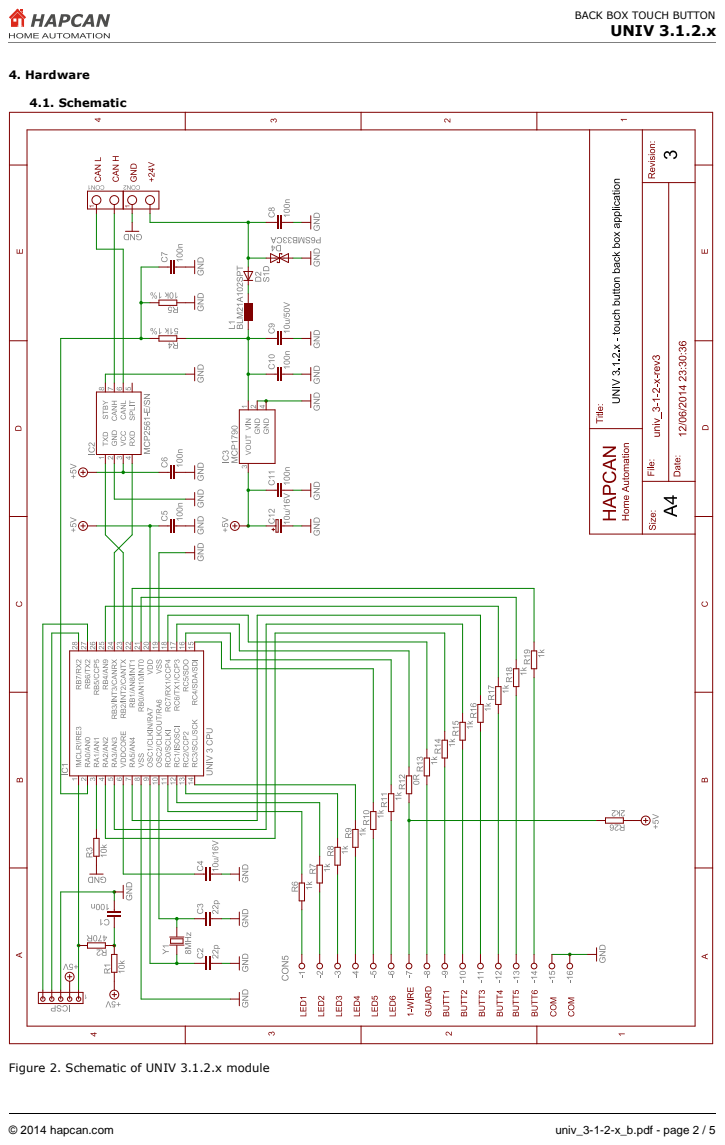
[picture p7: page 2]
4. Hardware; 4.1. Schematic

Figure 2. Schematic of UNIV 3.1.2.x module

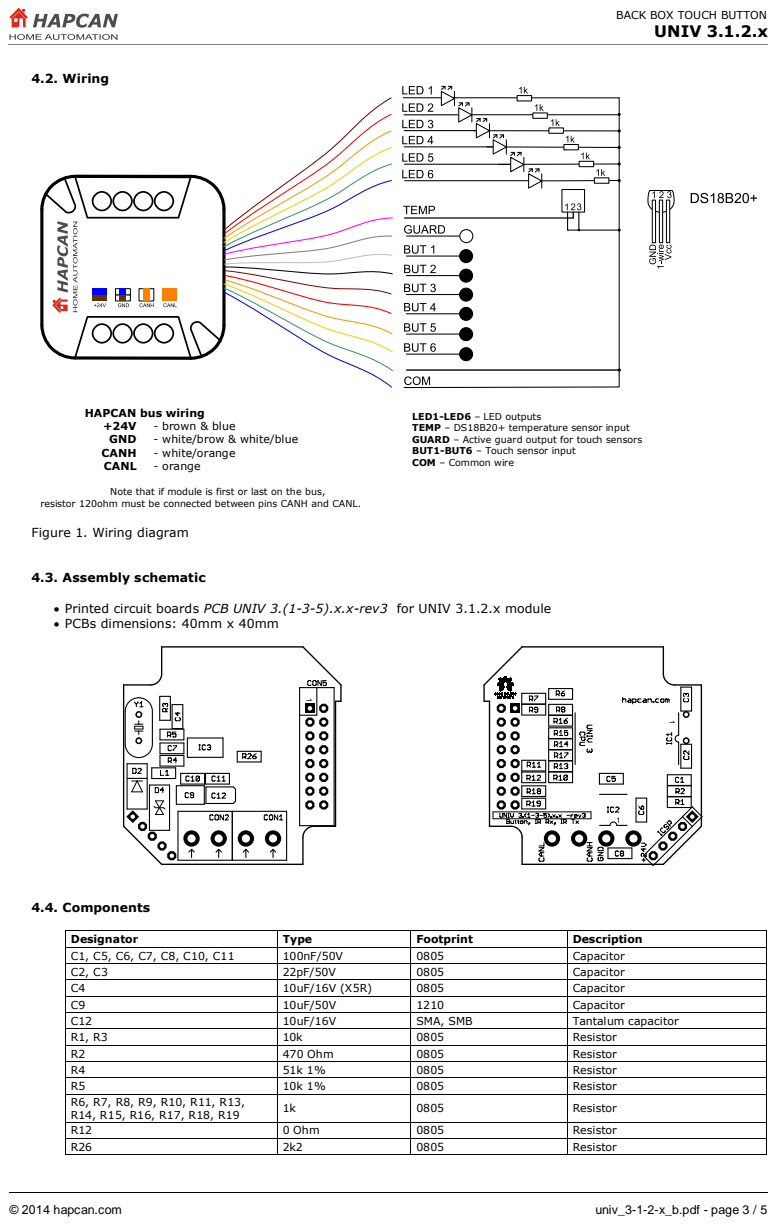
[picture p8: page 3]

LED1-LED6 – LED outputs
TEMP – DS18B20+ temperature sensor input
GUARD – Active guard output for touch sensors
BUT1-BUT6 – Touch sensor input
COM – Common wire

Note that if module is first or last on the bus,

resistor 120ohm must be connected between pins CANH and CANL.

• Printed circuit boards PCB UNIV 3.(1-3-5).x.x-rev3 for UNIV 3.1.2.x module
• PCBs dimensions: 40mm x 40mm

Designator | Type | Footprint | Description
C1, C5, C6, C7, C8, C10, C11 | 100nF/50V | 0805 | Capacitor
C2, C3 | 22pF/50V | 0805 | Capacitor
C4 | 10uF/16V (X5R) | 0805 | Capacitor
C9 | 10uF/50V | 1210 | Capacitor
C12 | 10uF/16V | SMA, SMB | Tantalum capacitor
R1, R3 | 10k | 0805 | Resistor
R2 | 470 Ohm | 0805 | Resistor
R4 | 51k 1% | 0805 | Resistor
R5 | 10k 1% | 0805 | Resistor
R6, R7, R8, R9, R10, R11, R13, R14, R15, R16, R17, R18, R19 | 1k | 0805 | Resistor

R12 | 0 Ohm | 0805 | Resistor
R26 | 2k2 | 0805 | Resistor

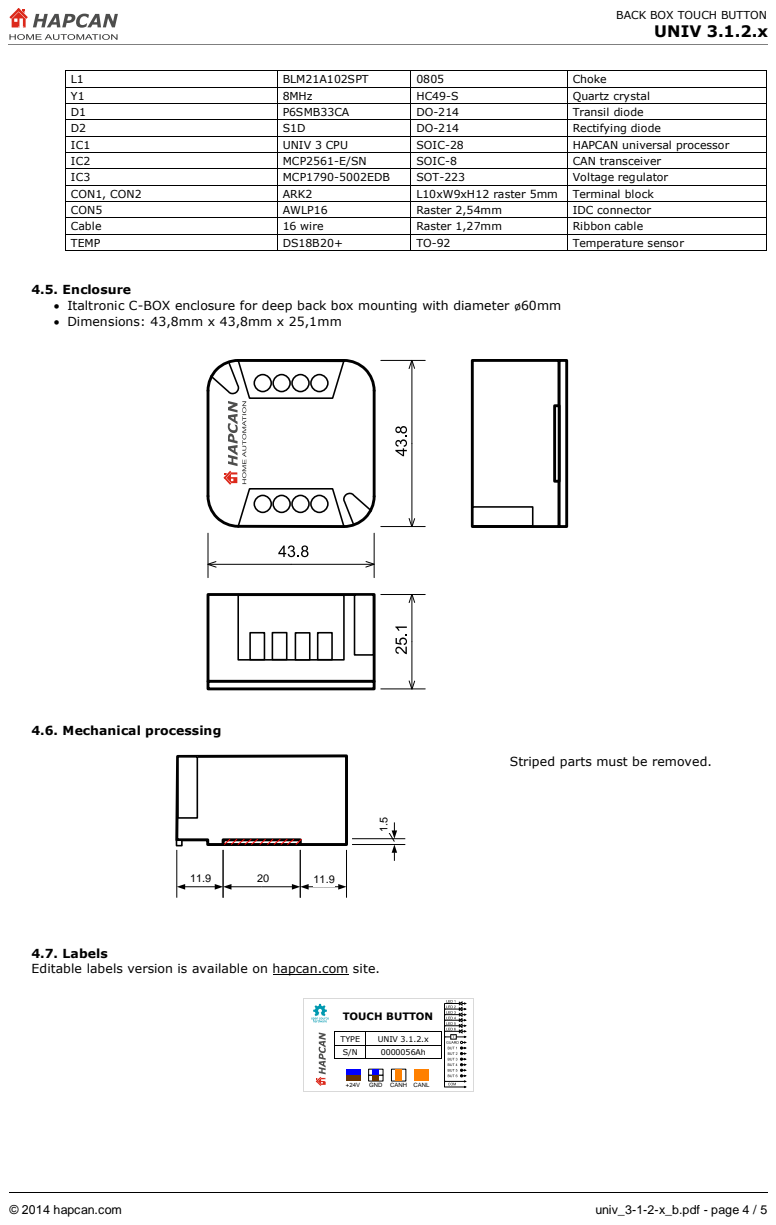
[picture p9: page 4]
4.6. Mechanical processing; TOUCH BUTTON; GND; CANH CANL

L1 | BLM21A102SPT | 0805 | Choke
Y1 | 8MHz | HC49-S | Quartz crystal
D1 | P6SMB33CA | DO-214 | Transil diode
D2 | S1D | DO-214 | Rectifying diode
IC1 | UNIV 3 CPU | SOIC-28 | HAPCAN universal processor
IC2 | MCP2561-E/SN | SOIC-8 | CAN transceiver
IC3 | MCP1790-5002EDB | SOT-223 | Voltage regulator
CON1, CON2 | ARK2 | L10xW9xH12 raster 5mm | Terminal block
CON5 | AWLP16 | Raster 2,54mm | IDC connector
Cable | 16 wire | Raster 1,27mm | Ribbon cable
TEMP | DS18B20+ | TO-92 | Temperature sensor

4.5. Enclosure
• Italtronic C-BOX enclosure for deep back box mounting with diameter ø60mm
• Dimensions: 43,8mm x 43,8mm x 25,1mm

Striped parts must be removed.

4.7. Labels
Editable labels version is available on hapcan.com site.

TYPE | UNIV 3.1.2.x
S/N | 0000056Ah

### 5. Commissioning

### 5.1. CPU voltage measurement

After verifying the correctness and quality of the soldering, the bus voltage should be connected while measuring the processor voltage. To do this, connect a voltmeter to pins 2 and 3 of the ICSP connector. Processor supply voltage should be about 5V.

Figure 3. CPU voltage measurement

### 5.2. Checking the CPU clock

Proper operation of the CPU can be checked by temporarily connecting the LED to pins 3 and 5 of the ICSP connector. When device is powered, the LED should light up four times in the sequence 1 second on - 1 second off
- 1 second on. The LED lights up only once for 50ms, if the processor is in programming mode.

Figure 4. Checking the CPU clock
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

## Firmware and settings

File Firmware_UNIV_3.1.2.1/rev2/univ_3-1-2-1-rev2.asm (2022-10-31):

;=============================================================================
;   MIT License
;
;   Copyright (c) 2022 HAPCAN Home Automation Project (http://hapcan.com)
;
;   Permission is hereby granted, free of charge, to any person obtaining a copy
;   of this software and associated documentation files (the "Software"), to deal
;   in the Software without restriction, including without limitation the rights
;   to use, copy, modify, merge, publish, distribute, sublicense, and/or sell
;   copies of the Software, and to permit persons to whom the Software is
;   furnished to do so, subject to the following conditions:
;
;   The above copyright notice and this permission notice shall be included in all
;   copies or substantial portions of the Software.
;
;   THE SOFTWARE IS PROVIDED "AS IS", WITHOUT WARRANTY OF ANY KIND, EXPRESS OR
;   IMPLIED, INCLUDING BUT NOT LIMITED TO THE WARRANTIES OF MERCHANTABILITY,
;   FITNESS FOR A PARTICULAR PURPOSE AND NONINFRINGEMENT. IN NO EVENT SHALL THE
;   AUTHORS OR COPYRIGHT HOLDERS BE LIABLE FOR ANY CLAIM, DAMAGES OR OTHER
;   LIABILITY, WHETHER IN AN ACTION OF CONTRACT, TORT OR OTHERWISE, ARISING FROM,
;   OUT OF OR IN CONNECTION WITH THE SOFTWARE OR THE USE OR OTHER DEALINGS IN THE
;   SOFTWARE.
;==============================================================================
;   Filename:              univ_3-1-2-1.asm
;   Associated diagram:    univ_3-1-2-x.sch
;   Author:                Jacek Siwilo                          
;   Note:                  6 channel touch button & temp module
;==============================================================================
;   Revision History
;   Rev:  Date:     Details:
;   0     08.2017   Initial version
;   1     08.2017   Improvement in Instr09
;   2     10.2022   Channel name added
;==============================================================================
;===  FIRMWARE DEFINITIONS  =================================================== 
;==============================================================================
    #define    ATYPE    .1                            ;application type [0-255]
    #define    AVERS    .2                         ;application version [0-255]
    #define    FVERS    .1                            ;firmware version [0-255]

    #define    FREV     .2                         ;firmware revision [0-65536]
;==============================================================================
;===  NEEDED FILES  ===========================================================
;==============================================================================
    LIST P=18F26K80                              ;directive to define processor
    #include <P18F26K80.INC>           ;processor specific variable definitions
    #include "univ_3-1-2-1-rev2.inc"                         ;project variables
INCLUDEDFILES   code    
    #include "univ3-routines-rev9.inc"                     ;UNIV 3 CPU routines
    #include "univ3-mTouch-rev1.inc"                ;UNIV 3 CPU mTouch routines
    #include "univ3-1-wire-rev0.inc"                          ;1-wire functions

;==============================================================================
;===  FIRMWARE CHECKSUM  ======================================================
;==============================================================================
FIRMCHKSM   code    0x001000
    DB      0x58, 0x26, 0x8B, 0xFF, 0xFF, 0xFF, 0xFF, 0xFF
;==============================================================================
;===  FIRMWARE ID  ============================================================
;==============================================================================
FIRMID      code    0x001010
    DB      0x30, 0x00, 0x03,ATYPE,AVERS,FVERS,FREV>>8,FREV
;            |     |     |     |     |     |     |_____|_____ firmware revision
;            |     |     |     |     |     |__________________ firmware version
;            |     |     |     |     |_____________________ application version
;            |     |     |     |______________________________ application type
;            |     |     |________________________________ hardware version '3'
;            |_____|______________________________________ hardware type 'UNIV'
;==============================================================================
;===  MOVED VECTORS  ==========================================================
;==============================================================================
;PROGRAM RESET VECTOR
FIRMRESET   code    0x1020
        goto    Main
;PROGRAM HIGH PRIORITY INTERRUPT VECTOR
FIRMHIGHINT code    0x1030
        call    HighInterrupt
        retfie
;PROGRAM LOW PRIORITY INTERRUPT VECTOR
FIRMLOWINT  code    0x1040
        call    LowInterrupt
        retfie

;==============================================================================
;===  FIRMWARE STARTS  ========================================================
;==============================================================================
FIRMSTART   code    0x001050
;------------------------------------------------------------------------------
;---  LOW PRIORITY INTERRUPT  -------------------------------------------------
;------------------------------------------------------------------------------
LowInterrupt
        movff   STATUS,STATUS_LOW           ;save STATUS register
        movff   WREG,WREG_LOW               ;save working register
        movff   BSR,BSR_LOW                 ;save BSR register
        movff   FSR0L,FSR0L_LOW             ;save other registers used in high int
        movff   FSR0H,FSR0H_LOW
        movff   FSR1L,FSR1L_LOW
        movff   FSR1H,FSR1H_LOW

    ;main firmware ready flag
        movlb   0x1
        btfss   FIRMREADY,0
        bra     ExitLowInterrupt            ;main firmware is not ready yet
    ;CAN buffer
        movlb   0x1
        btfsc   CANFULL,0                   ;check if CAN received anything
        call    CANInterrupt                ;proceed with CAN interrupt

ExitLowInterrupt
        movff   BSR_LOW,BSR                 ;restore BSR register
        movff   WREG_LOW,WREG               ;restore working register
        movff   STATUS_LOW,STATUS           ;restore STATUS register
        movff   FSR0L_LOW,FSR0L             ;restore other registers used in high int
        movff   FSR0H_LOW,FSR0H
        movff   FSR1L_LOW,FSR1L
        movff   FSR1H_LOW,FSR1H
    return
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

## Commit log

2014-03-25 hardware revision 2
    [pcb_univ_3-(1-3-5)-x-x-rev2.brd, pcb_univ_3-(1-3-5)-x-x-rev2.sch, univ_3-1-2-x-rev2.sch]
2014-03-25 firmware revision 0
    [univ_3-1-2-0-rev0-memory.xlsx]
2014-06-11 touch panel for Gira 55
    [touch_panel_gira-rev1.brd, touch_panel_gira-rev1.sch]
2014-12-04 hardware revision 1
    [pcb_touch_panel_gira-rev1.brd, pcb_touch_panel_gira-rev1.sch]
2014-12-07 hardware UNIV 3.1.2.x revision 2
    [pcb_univ_3-(1-3-5)-x-x-rev2.brd, pcb_univ_3-(1-3-5)-x-x-rev2.sch, univ_3-1-2-x-rev2.sch]
2014-12-07 hardware UNIV 3.1.2.x revision 3
    [pcb_univ_3-(1-3-5)-x-x-rev3.brd, pcb_univ_3-(1-3-5)-x-x-rev3.sch, univ_3-1-3-x-rev3.sch]
2014-12-07 hardware UNIV 3.1.2.x revision 4
    [pcb_univ_3-(1-3-5)-x-x-rev4.brd, pcb_univ_3-(1-3-5)-x-x-rev4.sch, univ_3-1-2-x-rev4.sch]
2017-08-11 firmware UNIV 3.1.2.1 rev0
    [univ_3-1-2-1-rev0-memory.xlsx]
2017-08-11 firmware UNIV 3.1.2.1 revision 0
    [univ_3-1-2-1-rev1-memory.xlsx]
2017-08-11 firmware UNIV 3.1.2.1 revision 1
    [univ_3-1-2-1-rev1-memory.xlsx]
2017-08-11 Revert "firmware UNIV 3.1.2.1 rev0"
    This reverts commit 87a67fa0d916f9b4e71768a0a2154504599c1edb.
    [univ_3-1-2-1-rev0-memory.xlsx]
2017-08-11 Revert "firmware UNIV 3.1.2.1 revision 0"
    This reverts commit 8a18a9a1b106eb16724a86efef1e2beefafe5c6c.
    [univ_3-1-2-1-rev1-memory.xlsx]
2017-08-11 Revert "Revert "firmware UNIV 3.1.2.1 rev0""
    This reverts commit cc69614edd5ef715979d3f1aa5d36d05fbfb089d.
    [univ_3-1-2-1-rev0-memory.xlsx]
2017-08-11 Revert "Revert "firmware UNIV 3.1.2.1 revision 0""
    This reverts commit 3e88b65fc98bc3f203823b8930acdd5187d8289f.
    [univ_3-1-2-1-rev1-memory.xlsx]
2022-10-31 firmware UNIV 3.1.2.1 revision 2
    [univ_3-1-2-1-rev2-memory.xlsx]

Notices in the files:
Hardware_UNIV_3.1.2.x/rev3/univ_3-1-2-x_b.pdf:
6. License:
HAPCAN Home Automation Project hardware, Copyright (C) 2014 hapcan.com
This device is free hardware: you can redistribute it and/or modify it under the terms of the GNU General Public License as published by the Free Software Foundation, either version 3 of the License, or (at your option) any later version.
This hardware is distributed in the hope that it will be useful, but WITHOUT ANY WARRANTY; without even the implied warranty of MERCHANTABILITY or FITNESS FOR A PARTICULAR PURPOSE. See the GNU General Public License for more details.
